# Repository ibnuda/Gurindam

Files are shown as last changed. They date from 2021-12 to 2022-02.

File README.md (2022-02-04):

# Gurindam

it's an [arisu](https://github.com/FateNozomi/arisu-pcb)-style keyboard that uses
a promicro as the controller.

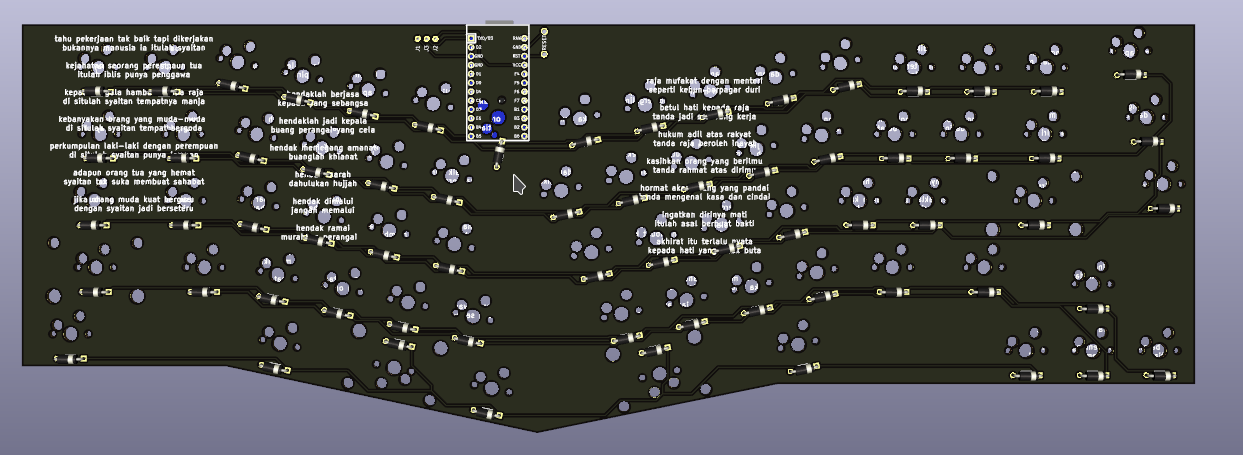
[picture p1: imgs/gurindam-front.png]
gurindam-front

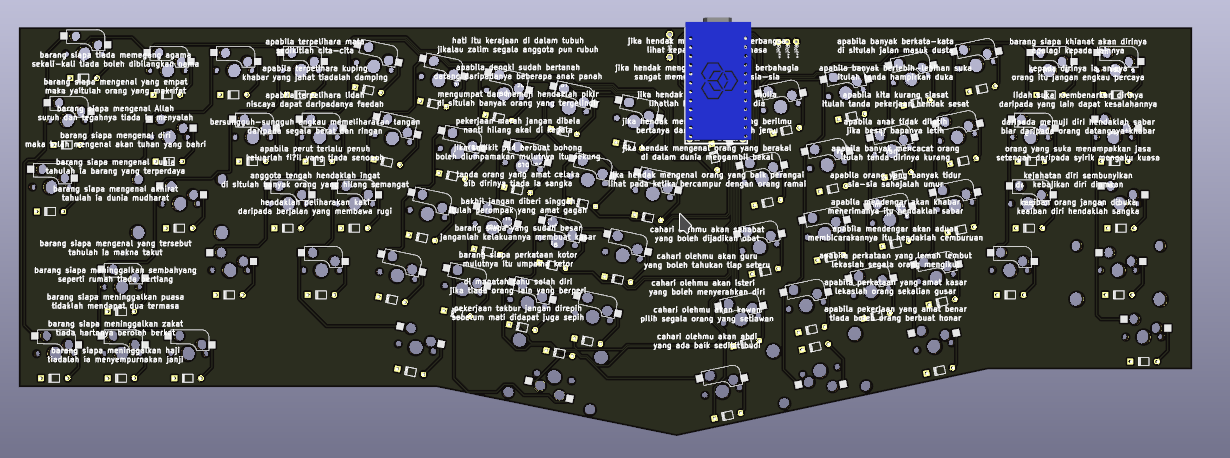
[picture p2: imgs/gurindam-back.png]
gurindam-back


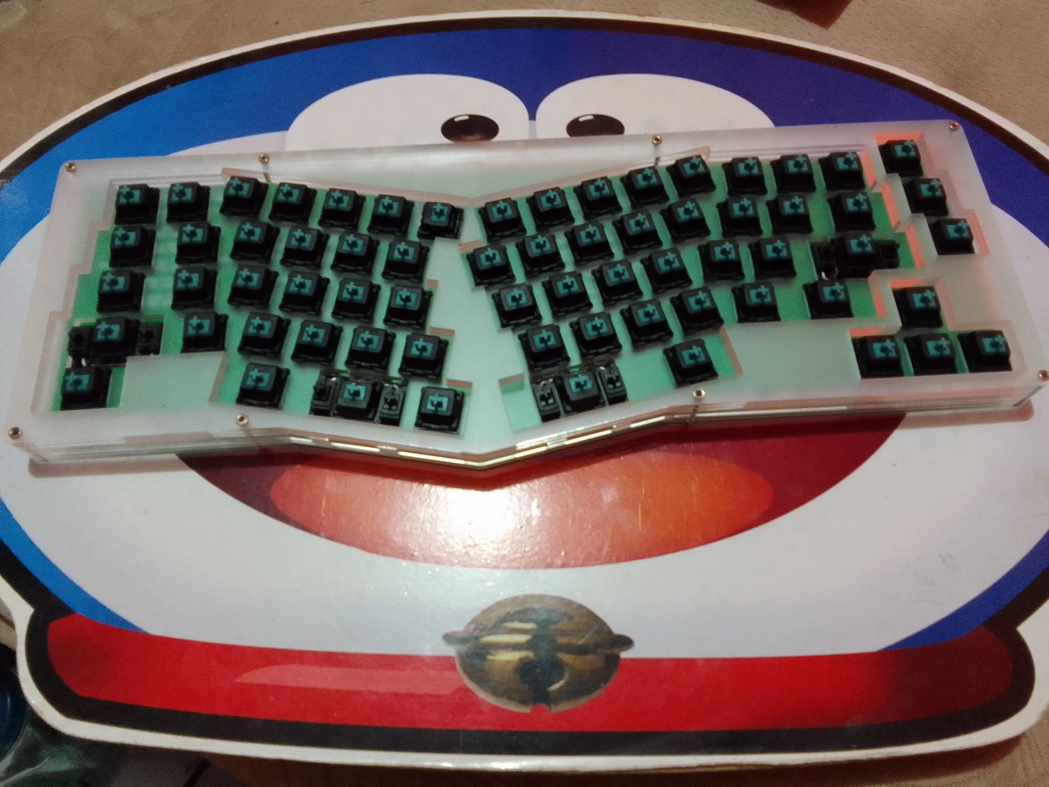
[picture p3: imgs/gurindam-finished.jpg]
gurindam finished


## About the name
[Gurindam](https://en.wikipedia.org/wiki/Gurindam) (Jawi: ڬوريندام) is a type of
irregular verse forms of traditional Indonesian and Malay poetry.
It is a combination of two clauses where the relative clause forms a line and is
thus linked to the second line, or the main clause.
Each pair of lines (stanza) provides complete ideas within the pair and has the
same rhyme in its end.
There is no limit on the number words per line and neither the rhythm per line is fixed.

## About the silks

The silk is Gurindam Dua Belas (Twelve Gurindam) of [Raja Ali Haji](https://en.wikipedia.org/wiki/Raja_Ali_Haji) written in 1847.

## My plea
If somehow you fabricate this design, I hope that you feed a filling meal to one
of your less-fortunate neighbours.

## License
CERN Open Hardware Licence Version 2 - Strongly Reciprocal

### Notes
If you have fabricated the pcb using these files prior 2022-01-25 and want to use
the plates in the `sandwich` directory, use plate v1 or v2.
But, if you fabricated the pcb using the files after 2022-01-25 and want to use
the plates in the `sandwich` directory, use v3.

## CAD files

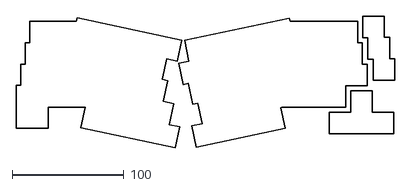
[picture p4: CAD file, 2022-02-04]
sandwich/caps-area-v3.dxf
338.5 x 117.6

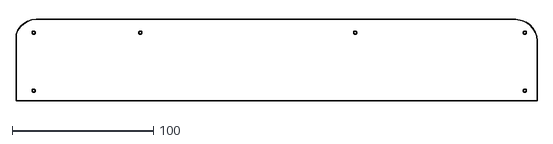
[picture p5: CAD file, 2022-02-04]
sandwich/plates-v3/back-feet-1.dxf
368.6 x 57.3

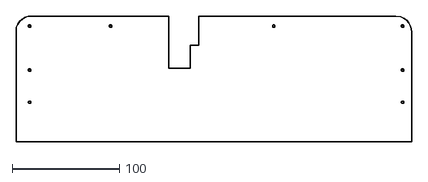
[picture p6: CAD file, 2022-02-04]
sandwich/plates-v3/back-feet-3.dxf
368.6 x 117.3

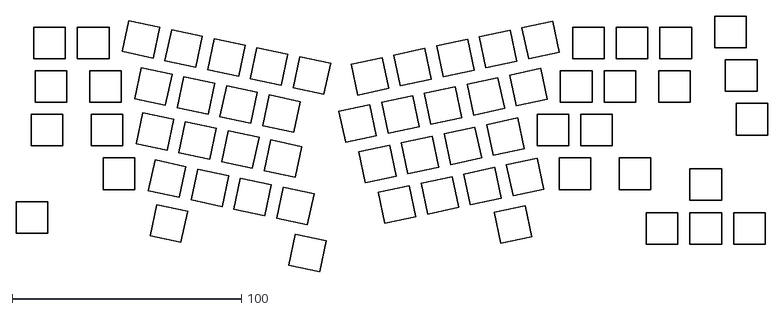
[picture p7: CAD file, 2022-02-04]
sandwich/switch-holes-v3.dxf
328.2 x 111.7

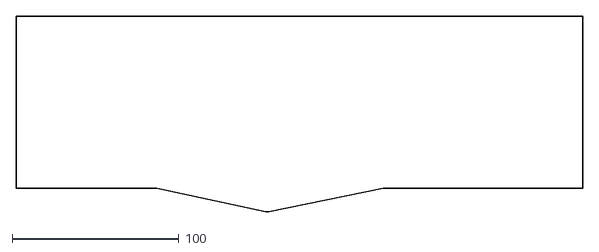
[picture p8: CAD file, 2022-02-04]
sandwich/pcb-shape-v3.dxf
339.3 x 116.8

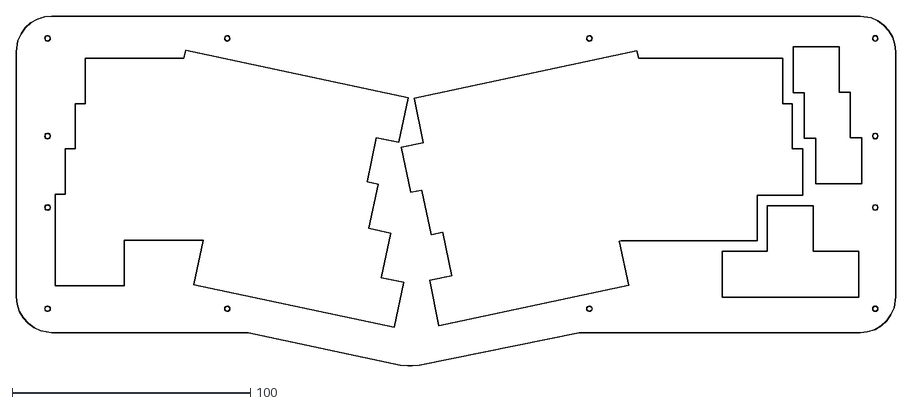
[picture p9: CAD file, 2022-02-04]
sandwich/plates-v3/top-plate.dxf
369.3 x 146.8

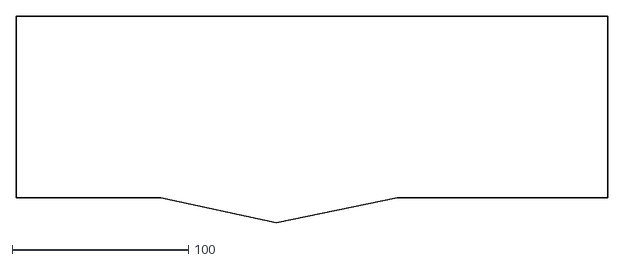
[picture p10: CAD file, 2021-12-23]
sandwich/base-shape-v2.dxf
335.3 x 116.8

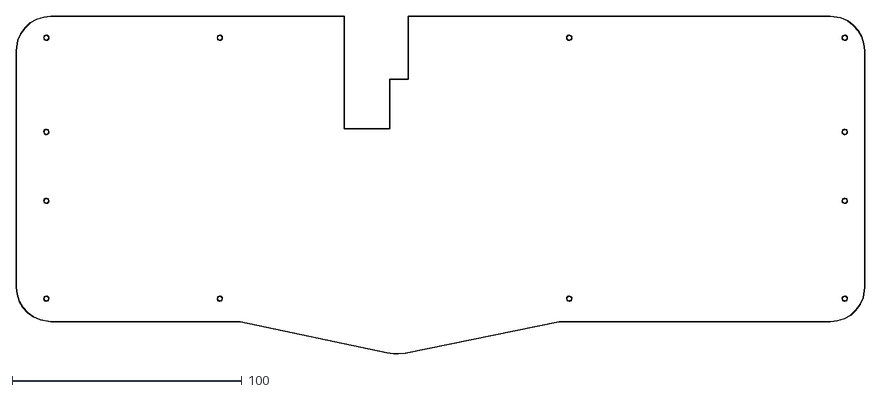
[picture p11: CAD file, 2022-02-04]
sandwich/plates-v3/bottom-plate.dxf
369.3 x 146.8

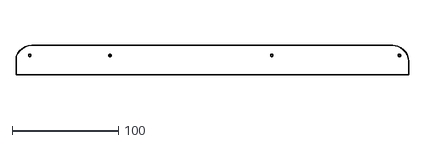
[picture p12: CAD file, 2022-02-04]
sandwich/plates-v3/back-feet-0.dxf
368.6 x 27.3

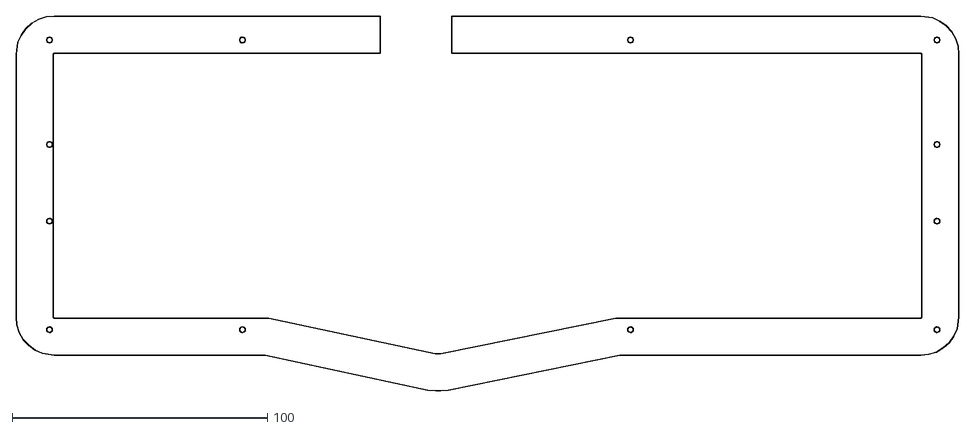
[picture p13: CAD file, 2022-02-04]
sandwich/plates-v3/middle-plate.dxf
369.3 x 146.8

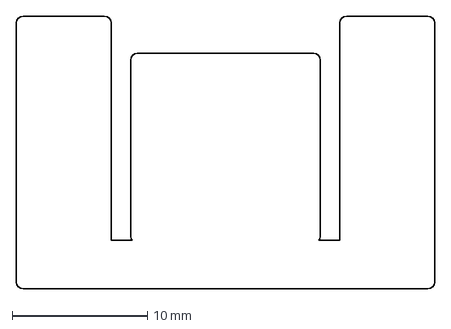
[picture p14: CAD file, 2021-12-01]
sandwich/2u-keebio.dxf
30.9 x 20.2 mm

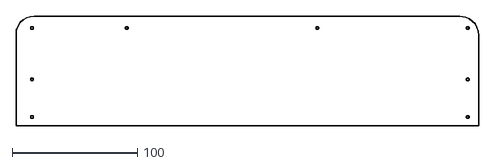
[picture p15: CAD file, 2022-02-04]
sandwich/plates-v3/back-feet-2.dxf
368.6 x 87.3

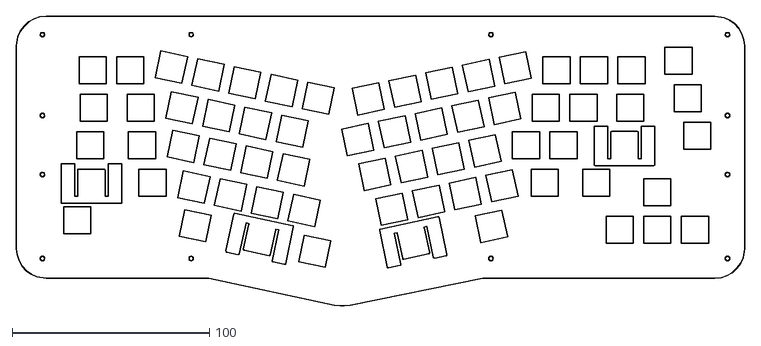
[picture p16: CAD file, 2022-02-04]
sandwich/plates-v3/switch-plate.dxf
369.3 x 146.8

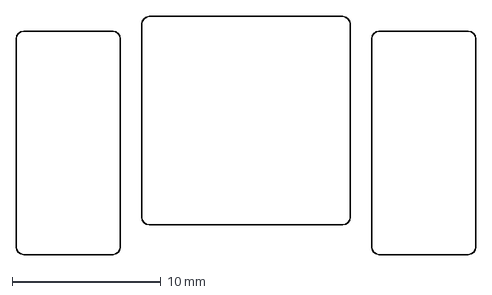
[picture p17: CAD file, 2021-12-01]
sandwich/2u-ai.dxf
30.9 x 16.0 mm

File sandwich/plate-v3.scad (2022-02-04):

screw_locations = [
    [ -27.5,  18 ],
    [ -27.5, -23 ],
    [ -27.5, -53 ],
    [ -27.5, -95.5 ],
    [ 48,    -95.5 ],
    [ 200,   -95.5 ],
    [ 320,   -95.5 ],
    [ 320,   -23 ],
    [ 320,   -53 ],
    [ 320,    18 ],
    [ 200,    18 ],
    [ 48,     18 ]
];

module
screw_holes()
{
    for (i = [0:len(screw_locations) - 1]) {
        translate(screw_locations[i]) circle(r = 1.1, $fn = 20);
    }
}

module
base_shape()
{
    offset(15) import("pcb-shape-v3.dxf");
}

module
pcb_shape()
{
    offset(0.5) import("pcb-shape-v3.dxf");
}

module
caps_area()
{
    import("caps-area-v3.dxf");
}

module 2u()
{
    union()
    {
        // color("red") translate([ -19.05, -9.525, 0 ])
        //     translate([ -0.0951, -0.257, 0 ]) import("2u.dxf");
        // rotate([ 0, 0, 180 ]) translate([ -19.05, -9.525, 0 ])
        //     translate([ -0.0951, -0.257, 0 ]) import("2u.dxf");
        // color("red") translate([ -19.05, 9.525, 0 ])
        //     import("2u-ai.dxf");
        // rotate([ 0, 0, 180 ]) translate([ -19.05, 9.525, 0 ])
        //     import("2u-ai.dxf");
        color("red") translate([ -19.05, 9.525, 0 ]) import("2u-keebio.dxf");
        // rotate([ 0, 0, 180 ]) translate([ -19.05, 9.525, 0 ])
        // import("2u-keebio.dxf");
    }
}

module
switch_holes()
{
    union()
    {
        import("switch-holes-v3.dxf");
        // right spacebar.
        translate([ 160.672807, -87.658576, 0 ]) rotate([ 0, 0, 192 ]) 2u();
        // left spacebar.
        translate([ 82.646455, -85.864146, 0 ]) rotate([ 0, 0, 168 ]) 2u();
        // left shift.
        translate([ -2.595313, -57.15, 0 ]) rotate([ 0, 0, 0 ]) 2u();
        // enter
        translate([ 267.762122, -38.1, 0 ]) rotate([ 0, 0, 0 ]) 2u();
    }
}

module
promicro_and_reset_area()
{
    polygon(points = [
        [ 102, 30 ],
        [ 102, -21.5 ],
        [ 122, -21.5 ],
        [ 122, 0 ],
        [ 130, 0 ],
        [ 130, 30 ],
    ]);
}

module
base_plate()
{
    difference()
    {
        base_shape();
        screw_holes();
    }
}

module
bottom_plate()
{
    difference()
    {
        base_shape();
        screw_holes();
        promicro_and_reset_area();
    }
}

module
back_feet_3()
{
    difference()
    {
        intersection()
        {
            base_shape();
            translate([ -40, -90, 0 ])
                square(size = [ 400, 600 ], center = false);
        }
        screw_holes();
        promicro_and_reset_area();
    }
}

module
back_feet_2()
{
    difference()
    {
        intersection()
        {
            base_shape();
            translate([ -40, -60, 0 ])
                square(size = [ 400, 600 ], center = false);
        }
        screw_holes();
    }
}

module
back_feet_1()
{
    difference()
    {
        intersection()
        {
            base_shape();
            translate([ -40, -30, 0 ])
                square(size = [ 400, 600 ], center = false);
        }
        screw_holes();
    }
}

module
back_feet_0()
{
    difference()
    {
        intersection()
        {
            base_shape();
            translate([ -40, 0, 0 ])
                square(size = [ 400, 600 ], center = false);
        }
        screw_holes();
    }
}

module
middle_plate()
{
    difference()
    {
        base_plate();
        pcb_shape();
        promicro_and_reset_area();
    }
}

module
switch_plate()
{
    difference()
    {
        base_plate();
        switch_holes();
    }
}

module
top_plate()
{
    difference()
    {
        base_plate();
        caps_area();
    }
}

rotate([ 6, 0, 0 ]) translate([ 0, 0, 9 ]) union()
{
     translate([ 0, 0, -12]) color("blue")  linear_extrude(height = 3) back_feet_0();
     translate([ 0, 0, -9 ]) color("red")   linear_extrude(height = 3) back_feet_1();
     translate([ 0, 0, -6 ]) color("green") linear_extrude(height = 3) back_feet_2();
     translate([ 0, 0, -3 ]) color("blue")  linear_extrude(height = 3) back_feet_3();
     translate([ 0, 0, 0 ])  color("green") linear_extrude(height = 3) bottom_plate();
     translate([ 0, 0, 3 ])  color("blue")  linear_extrude(height = 3) middle_plate();
     translate([ 0, 0, 6 ])  color("red")   linear_extrude(height = 3) middle_plate();
     translate([ 0, 0, 9 ])  color("green") linear_extrude(height = 3) switch_plate();
     translate([ 0, 0, 12 ]) color("blue")  linear_extrude(height = 3) top_plate();

     translate([ 0, 0, 15 ]) color("red")   linear_extrude(height = 3) top_plate();
}

// translate([0, 0, 0])    bottom_plate();
// translate([0, -150, 0]) middle_plate();
// translate([0,  0,   0]) middle_plate();
// translate([0,  150, 0]) switch_plate();
// translate([0,  300, 0]) top_plate();
// translate([0,  450, 0]) top_plate();
// translate([0,  580, 0]) back_feet_3();
// translate([0,  680, 0]) back_feet_2();
// translate([0,  780, 0]) back_feet_1();
// translate([0,  820, 0]) back_feet_0();

// bottom_plate();
// middle_plate();
// middle_plate();
// switch_plate();
// top_plate();
// top_plate();
// back_feet_3();
// back_feet_2();
// back_feet_1();
// back_feet_0();

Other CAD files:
sandwich/2u.dxf
sandwich/plates-v2/top-plate.dxf
sandwich/plates/plate-middle.dxf
sandwich/plates-v2/feet-2.dxf
sandwich/plate-v2.scad
sandwich/plate.scad
sandwich/base-shape.dxf
sandwich/caps-area.dxf
sandwich/pcb-shape.dxf
sandwich/plates-v2/bottom-plate.dxf
sandwich/plates-v2/feet-0.dxf
sandwich/plates-v2/feet-1.dxf
sandwich/plates-v2/feet-3.dxf
sandwich/plates-v2/middle-plate.dxf
sandwich/plates-v2/switch-plate.dxf
sandwich/plates/plate-bottom.dxf
sandwich/plates/plate-switch.dxf
sandwich/plates/plate-top.dxf
sandwich/switch-holes.dxf

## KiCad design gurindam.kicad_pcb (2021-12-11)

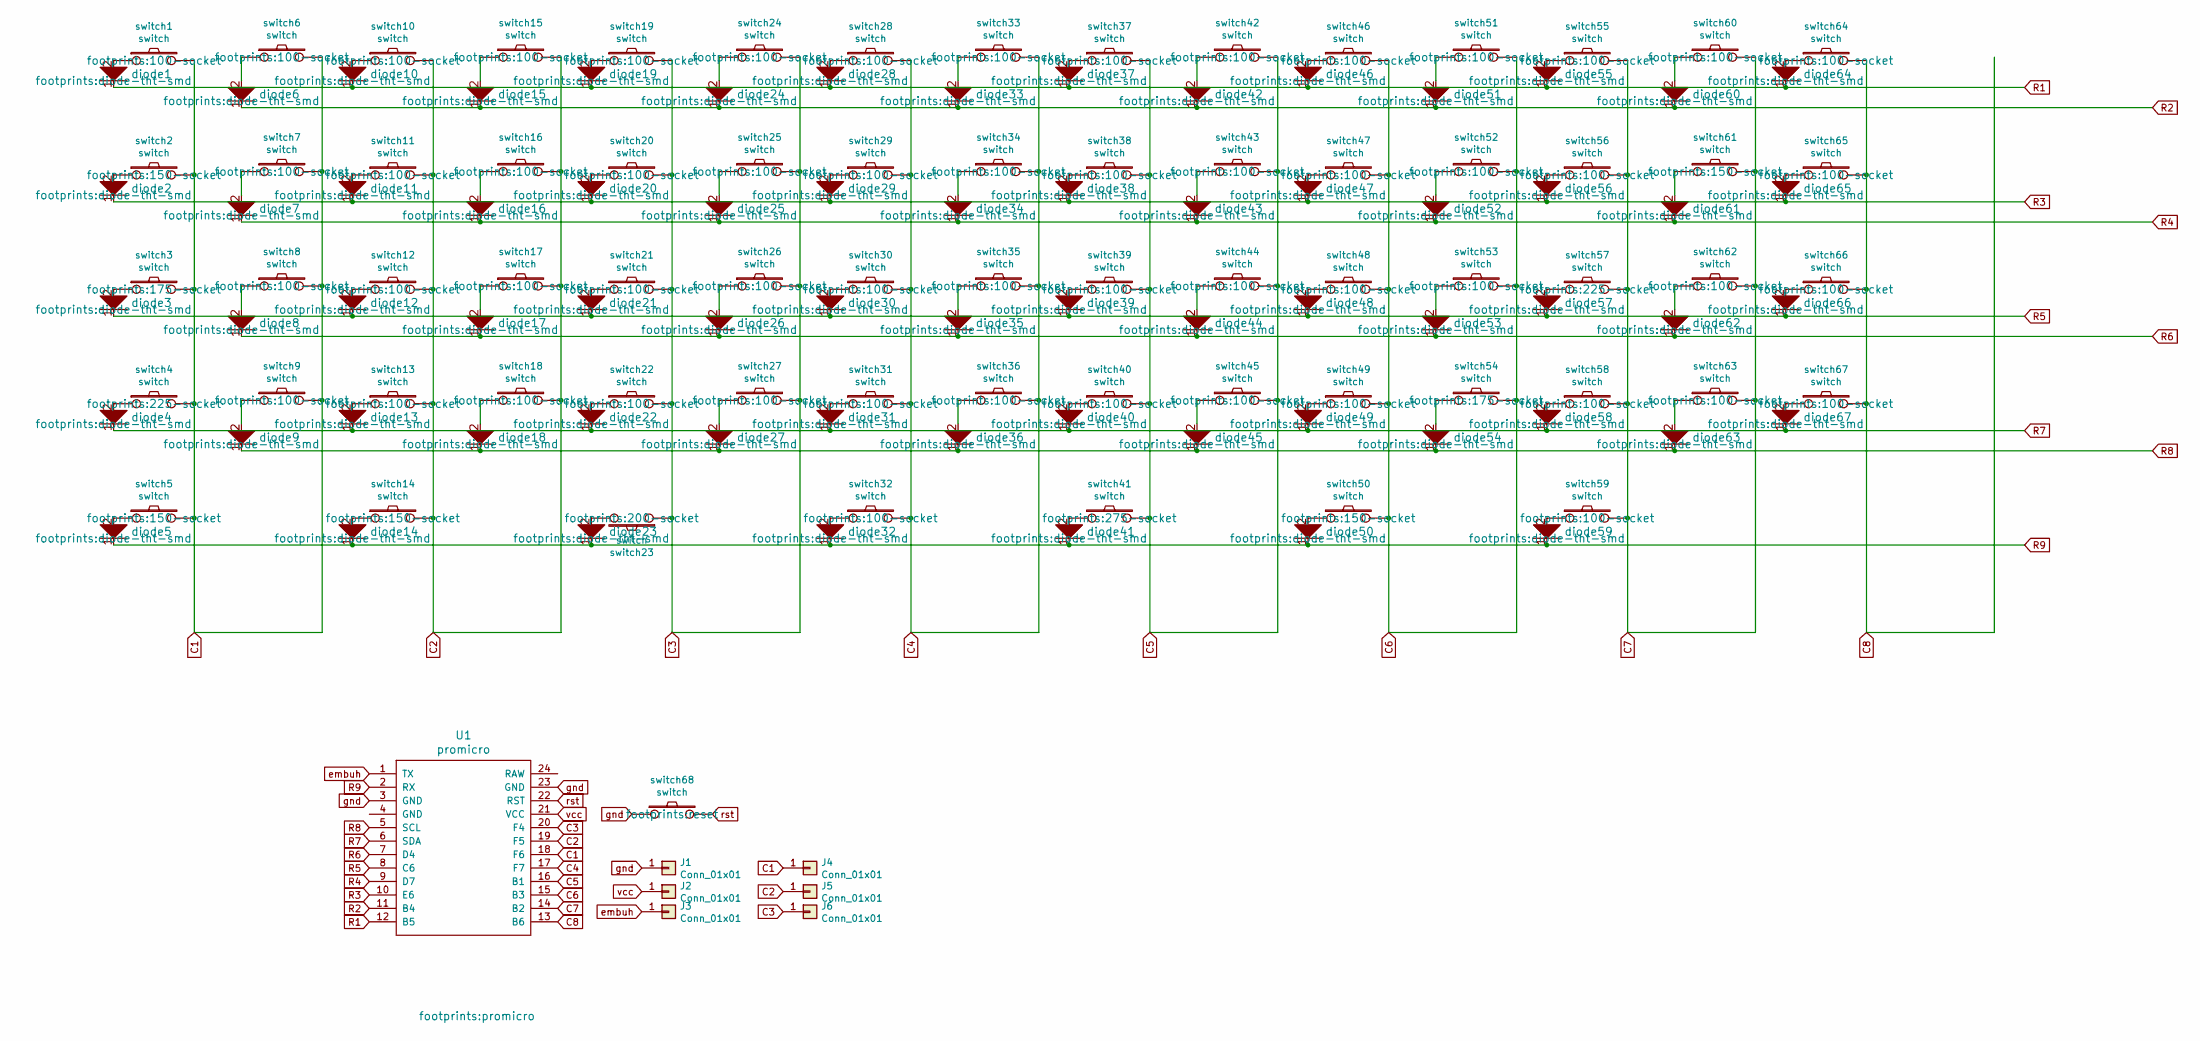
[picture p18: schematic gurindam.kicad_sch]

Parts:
J1, J2, J3, J4, J5, J6: Conn_01x01; wirepad
U1: promicro
diode1, diode2, diode3, diode4, diode5, diode6, diode7, diode8, diode9, diode10, diode11, diode12, diode13, diode14, diode15, diode16, diode17, diode18, diode19, diode20, diode21, diode22, diode23, diode24, diode25, diode26, diode27, diode28, diode29, diode30, diode31, diode32, diode33, diode34, diode35, diode36, diode37, diode38, diode39, diode40, diode41, diode42, diode43, diode44, diode45, diode46, diode47, diode48, diode49, diode50, diode51, diode52, diode53, diode54, diode55, diode56, diode57, diode58, diode59, diode60, diode61, diode62, diode63, diode64, diode65, diode66, diode67: diode; diode-tht-smd
switch1, switch6, switch7, switch8, switch9, switch10, switch11, switch12, switch13, switch15, switch16, switch17, switch18, switch19, switch20, switch21, switch22, switch24, switch25, switch26, switch27, switch28, switch29, switch30, switch31, switch32, switch33, switch34, switch35, switch36, switch37, switch38, switch39, switch40, switch42, switch43, switch44, switch45, switch46, switch47, switch48, switch49, switch51, switch52, switch53, switch55, switch56, switch58, switch59, switch60, switch62, switch63, switch64, switch65, switch66, switch67: switch; 100-socket
switch2, switch5, switch14, switch50, switch61: switch; 150-socket
switch3, switch54: switch; 175-socket
switch4, switch57: switch; 225-socket
switch23: switch; 200-socket
switch41: switch; 275-socket
switch68: switch; reset

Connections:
C1: J4.1, U1.18 (F6), switch1.2, switch2.2, switch3.2, switch4.2, switch5.2, switch6.2, switch7.2, switch8.2, switch9.2
C2: J5.1, U1.19 (F5), switch10.2, switch11.2, switch12.2, switch13.2, switch14.2, switch15.2, switch16.2, switch17.2, switch18.2
C3: J6.1, U1.20 (F4), switch19.2, switch20.2, switch21.2, switch22.2, switch23.1, switch24.2, switch25.2, switch26.2, switch27.2
C4: U1.17 (F7), switch28.2, switch29.2, switch30.2, switch31.2, switch32.2, switch33.2, switch34.2, switch35.2, switch36.2
C5: U1.16 (B1), switch37.2, switch38.2, switch39.2, switch40.2, switch41.2, switch42.2, switch43.2, switch44.2, switch45.2
C6: U1.15 (B3), switch46.2, switch47.2, switch48.2, switch49.2, switch50.2, switch51.2, switch52.2, switch53.2, switch54.2
C7: U1.14 (B2), switch55.2, switch56.2, switch57.2, switch58.2, switch59.2, switch60.2, switch61.2, switch62.2, switch63.2
C8: U1.13 (B6), switch64.2, switch65.2, switch66.2, switch67.2
unnamed: diode1.2, switch1.1
unnamed: diode2.2, switch2.1
unnamed: diode3.2, switch3.1
unnamed: diode4.2, switch4.1
unnamed: diode5.2, switch5.1
unnamed: diode6.2, switch6.1
unnamed: diode7.2, switch7.1
unnamed: diode8.2, switch8.1
unnamed: diode9.2, switch9.1
unnamed: diode10.2, switch10.1
unnamed: diode11.2, switch11.1
unnamed: diode12.2, switch12.1
unnamed: diode13.2, switch13.1
unnamed: diode14.2, switch14.1
unnamed: diode15.2, switch15.1
unnamed: diode16.2, switch16.1
unnamed: diode17.2, switch17.1
unnamed: diode18.2, switch18.1
unnamed: diode19.2, switch19.1
unnamed: diode20.2, switch20.1
unnamed: diode21.2, switch21.1
unnamed: diode22.2, switch22.1
unnamed: diode23.2, switch23.2
unnamed: diode24.2, switch24.1
unnamed: diode25.2, switch25.1
unnamed: diode26.2, switch26.1
unnamed: diode27.2, switch27.1
unnamed: diode28.2, switch28.1
unnamed: diode29.2, switch29.1
unnamed: diode30.2, switch30.1
unnamed: diode31.2, switch31.1
unnamed: diode32.2, switch32.1
unnamed: diode33.2, switch33.1
unnamed: diode34.2, switch34.1
unnamed: diode35.2, switch35.1
unnamed: diode36.2, switch36.1
unnamed: diode37.2, switch37.1
unnamed: diode38.2, switch38.1
unnamed: diode39.2, switch39.1
unnamed: diode40.2, switch40.1
unnamed: diode41.2, switch41.1
unnamed: diode42.2, switch42.1
unnamed: diode43.2, switch43.1
unnamed: diode44.2, switch44.1
unnamed: diode45.2, switch45.1
unnamed: diode46.2, switch46.1
unnamed: diode47.2, switch47.1
unnamed: diode48.2, switch48.1
unnamed: diode49.2, switch49.1
unnamed: diode50.2, switch50.1
unnamed: diode51.2, switch51.1
unnamed: diode52.2, switch52.1
unnamed: diode53.2, switch53.1
unnamed: diode54.2, switch54.1
unnamed: diode55.2, switch55.1
unnamed: diode56.2, switch56.1
unnamed: diode57.2, switch57.1
unnamed: diode58.2, switch58.1
unnamed: diode59.2, switch59.1
unnamed: diode60.2, switch60.1
unnamed: diode61.2, switch61.1
unnamed: diode62.2, switch62.1
unnamed: diode63.2, switch63.1
unnamed: diode64.2, switch64.1
unnamed: diode65.2, switch65.1
unnamed: diode66.2, switch66.1
unnamed: diode67.2, switch67.1
R1: U1.12 (B5), diode1.1, diode10.1, diode19.1, diode28.1, diode37.1, diode46.1, diode55.1, diode64.1
R2: U1.11 (B4), diode6.1, diode15.1, diode24.1, diode33.1, diode42.1, diode51.1, diode60.1
R3: U1.10 (E6), diode2.1, diode11.1, diode20.1, diode29.1, diode38.1, diode47.1, diode56.1, diode65.1
R4: U1.9 (D7), diode7.1, diode16.1, diode25.1, diode34.1, diode43.1, diode52.1, diode61.1
R5: U1.8 (C6), diode3.1, diode12.1, diode21.1, diode30.1, diode39.1, diode48.1, diode57.1, diode66.1
R6: U1.7 (D4), diode8.1, diode17.1, diode26.1, diode35.1, diode44.1, diode53.1, diode62.1
R7: U1.6 (SDA), diode4.1, diode13.1, diode22.1, diode31.1, diode40.1, diode49.1, diode58.1, diode67.1
R8: U1.5 (SCL), diode9.1, diode18.1, diode27.1, diode36.1, diode45.1, diode54.1, diode63.1
R9: U1.2 (RX), diode5.1, diode14.1, diode23.1, diode32.1, diode41.1, diode50.1, diode59.1
embuh: J3.1, U1.1 (TX)
gnd: J1.1, U1.3 (GND), U1.23 (GND), switch68.1
rst: U1.22 (RST), switch68.2
vcc: J2.1, U1.21 (VCC)

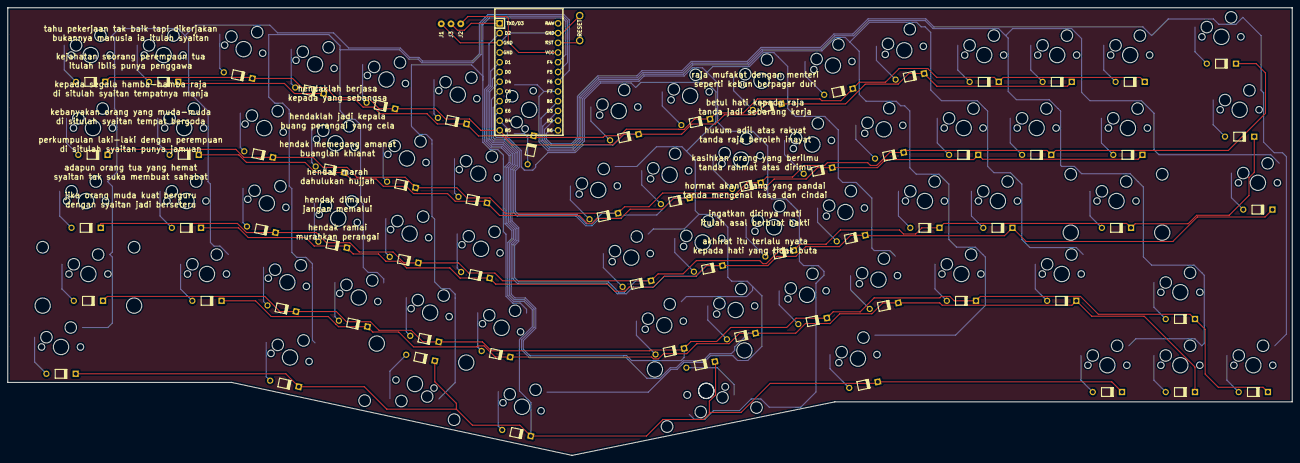
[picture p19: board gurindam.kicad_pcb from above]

Board: 2 copper layers, 335.3 x 116.8 mm, 139 parts (0 on the bottom side), 88 nets.

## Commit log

2021-11-26 init commit.
    [gurindam.kicad_pcb, gurindam.sch]
2021-11-27 wired the columns.
    [gurindam.kicad_pcb]
2021-11-30 hotswap socket.
    [gurindam.kicad_pcb, gurindam.sch]
2021-12-01 stacked acrylic case.
    [2u-ai.dxf, 2u-keebio.dxf, 2u.dxf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]
2021-12-10 fixed 275.
    [gurindam.kicad_pcb, plate.scad]
2021-12-23 stacked acry. v2.
    [base-shape-v2.dxf, bottom-plate.dxf, feet-0.dxf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]
2022-01-26 kicad 6 and moved the rightside 2mm.
    [gurindam.kicad_sch, plate-v2.scad]
2022-02-04 plates v3.
    [back-feet-0.dxf, back-feet-1.dxf, back-feet-2.dxf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]
2022-02-04 just to cover my ass in case someone is butthurt.
